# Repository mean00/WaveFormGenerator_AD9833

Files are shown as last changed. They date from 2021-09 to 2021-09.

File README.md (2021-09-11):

# WaveFormGenerator_AD9833

NB: The old version using an Arduino nano is on the legacy_atmel branch.

Simple waveform generator, using AD9833 + rotary encoder + SSD1306 oled screen.
It can output triangle/sinusoidal/rectangular waveforms.

That project is using lnArduino and requires a GD32F1/GD32F3/GD32VF1 or STM32F1 (bluepill)

Build instruction :
* edit platformConfig to specify your toolchain location
* edit mcuSelect.cmake to select your chip (default it GD32F1/STM32F1)
* mkdir build
* cd build && cmake ..
* make

Careful on the opamp.
Take one that is :
* Rail to rail
* Have high enough V/us rising time
* Have high enough gain x bandwidth ratio

With a MCP602 as amplifider, the signal is good till ~ 350 kHz
With a LM358 it's much lower, like ~ 150 kHZ

The square signal is directly from the ad9833 to avoid it being smoothed by the opamp.

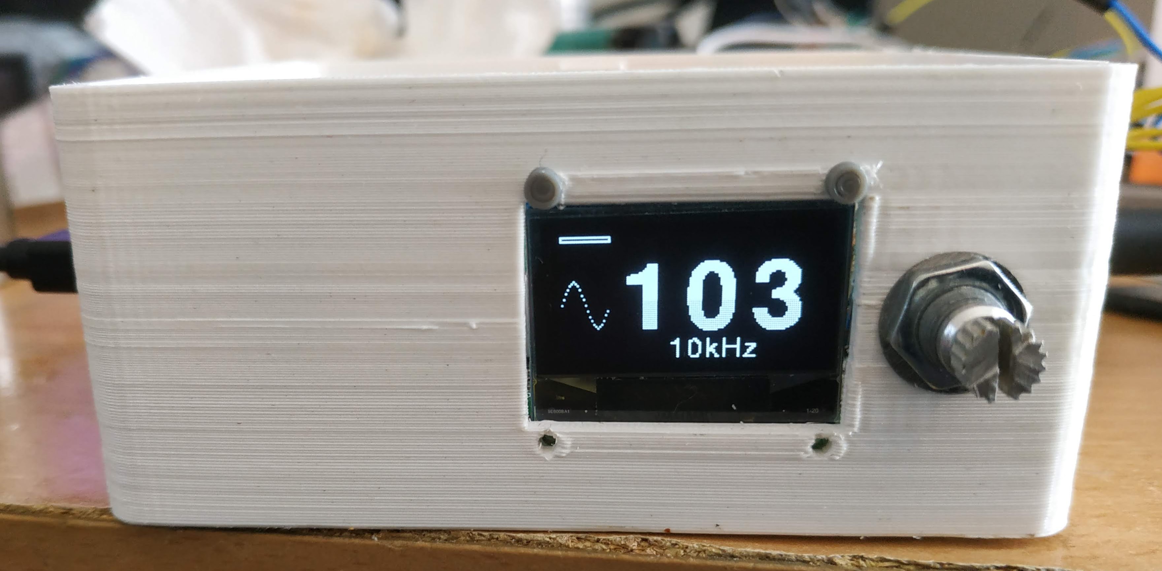
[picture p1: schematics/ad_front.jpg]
front

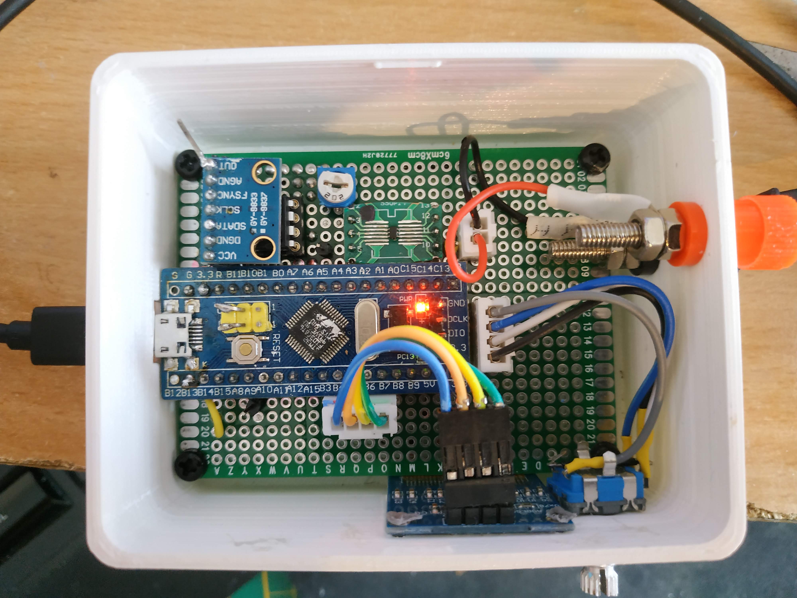
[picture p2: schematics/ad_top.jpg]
top

schem

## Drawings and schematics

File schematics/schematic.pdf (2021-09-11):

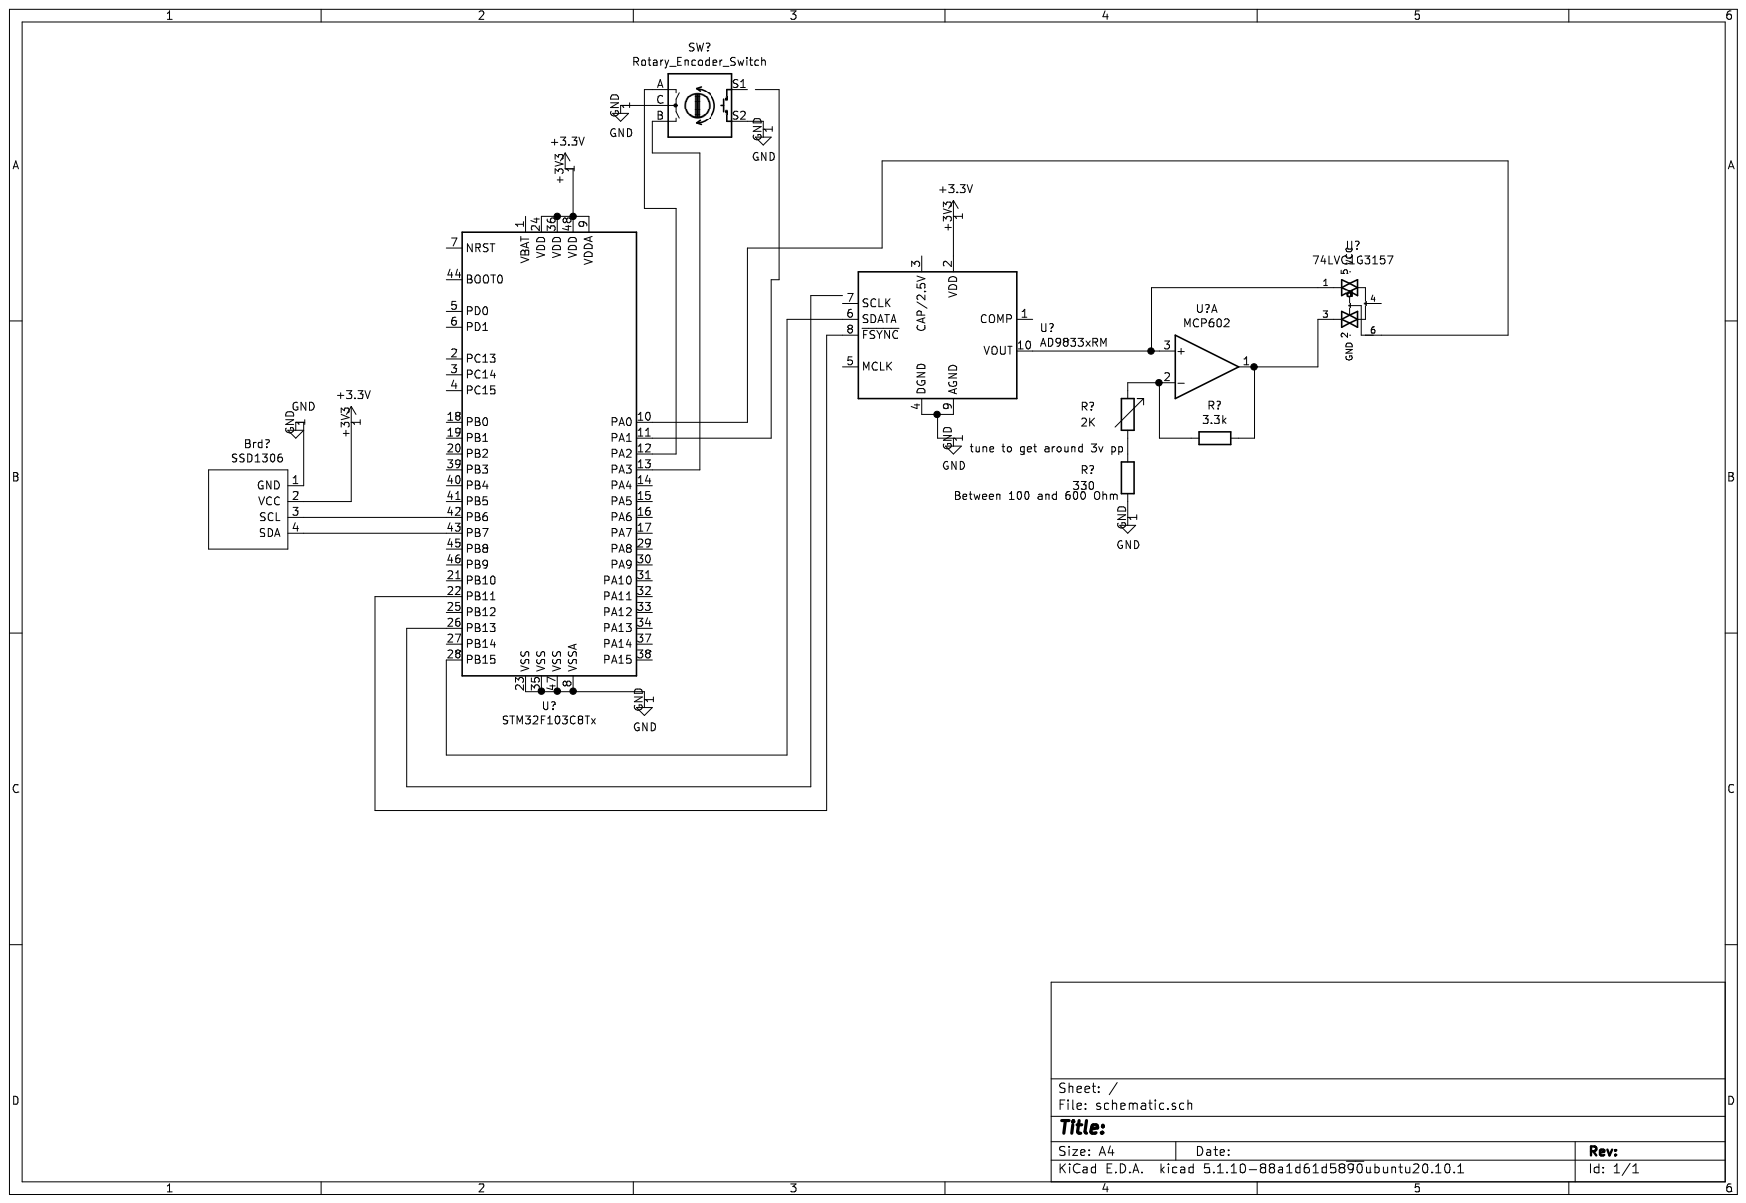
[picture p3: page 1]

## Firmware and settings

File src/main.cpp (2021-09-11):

//
//

#include "lnArduino.h"
#include "lnSPI.h"
#include "simplerAD9833.h"
#include "libraries/simplerAD9833/simplerAD9833.h"

#include "RotaryEncoder.h"

#include "libraries/simplerSSD1306/ssd1306_i2c_lnGd32vf103.h" // works also with gd32f1/Stm32f1
#include "fonts/FreeSans7pt7b.h"
#include "fonts/FreeSansBold24pt7b.h"

#include "wavePinout.h"
#include "wav_run.h"
#include "wav_display.h"

simplerAD9833 *ad;
OLED_lnGd32 *ssd1306;
lnRotary *rotary;
WavDisplay *display;
ActionInterface *action;

void amp(bool onoff)
{
    digitalWrite(AD9833_AMP, !onoff);
}

/**
 * 
 */
void setup()
{
    pinMode(LN_SYSTEM_LED,OUTPUT);    
    pinMode(AD9833_AMP,OUTPUT);    
    
    // ad9833
    
    digitalWrite(LN_SYSTEM_LED,0);
    Logger("Starting AD9833...");
    hwlnSPIClass *spi=new hwlnSPIClass(AD9833_SPI);
    ad=new simplerAD9833(spi,AD9833_CS);
    
    // ssd now
    lnI2C *i2c=new lnI2C(SSD1306_I2C,SSD1306_SPEED);
    i2c->begin(SSD1306_ADR);
    ssd1306=new OLED_lnGd32( *i2c, -1);
    ssd1306->begin();
    ssd1306->setFontFamily(&FreeSans7pt7b,&FreeSansBold24pt7b,&FreeSansBold24pt7b);
    ssd1306->setFontSize(OLEDCore::SmallFont);
    //
    display=new WavDisplay(ssd1306);
    // rotary
    rotary=new lnRotary(ROTARY_PUSH,ROTARY_LEFT,ROTARY_RIGHT);    
    action=createActionInterface();
    
}
/**
 * 
 */
void redraw()
{
    char fq[20];
    action->getFrequencyAsString(fq,19);  
    Selection sel=action->selection();
    WaveForm wf=action->getWaveForm();    
    ssd1306->clrScr();
    display->drawFrequency(fq);    
    bool hl;
    
    if(sel==TOP_SELECTION)
    {
        display->drawTab(action->selectionIndex());
    }
    
     if(sel==WAVEFORM_SELECTION) hl=true; else hl=false;
    display->displayWaveForme(wf,hl);   

    
#define DIGIT(sl,dex)     if(sel==sl) hl=true; else hl=false; \
    display->drawDigit(dex, action->getNumber(dex),hl);
    
    DIGIT(HIDIGIT_SELECTION,0)
    DIGIT(LODIGIT_SELECTION,1)
    DIGIT(SCALE_SELECTION,  2)
    
    ssd1306->update();
}
/**
 * 
 * @param fq
 * @param wf
 */
void updateAD9833(int fq, WaveForm wf)
{
    switch(wf)
    {
        case WAVE_SINE      : ad->setWaveForm(simplerAD9833::Sine);amp(true);break;
        case WAVE_TRIANGLE  : ad->setWaveForm(simplerAD9833::Triangle);amp(true);break;
        case WAVE_SQUARE    : ad->setWaveForm(simplerAD9833::Square);amp(false);break;
        default             : xAssert(0);break;
    }
    ad->setFrequency(fq);
}
/**
 * 
 */
void loop()
{
    Logger("Entering main app...\n");
    int onoff=0;
    //
    ssd1306->clrScr();
    ssd1306->update();

    
    // use safe default
    ad->setFrequency(10*1000);
    ad->setWaveForm(simplerAD9833::Sine);
    amp(true);
    ad->enable();
    
    rotary->start();
    redraw();
    while(1)
    {
       lnRotary::EVENTS  event=rotary->waitForEvent(1000);
       int count=rotary->getCount();
       if(event)
       {
            if(action->run(event,count))
            {
                updateAD9833(action->getFrequency(),action->getWaveForm());
                
                redraw();
            }
       }
    }
   
}
// EOF

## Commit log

2017-10-25 [WavForm] Switch to u8g2
2017-10-25 [wav] Fix push button + better display
2017-10-25 [wav] mostly working, need a better management of push button
2017-12-17 [wavForm] Change Fsync pin to D5 + cleanup display
2017-12-18 [waveForm] Use interrupts for rotary encoder
2017-12-18 [WavForm] Switch to interrupt driven rotary encoder
2017-12-18 [wavForm] push button, not working so well
2017-12-18 [wavForm] proper push button management
2019-08-08 [schematic] update schematic with SN74LVC3157
    [waveform.fzz]
2021-09-10 add schematic
    [schematic.kicad_pcb, schematic.sch]
2021-09-11 update schematic
2021-09-11 full schematic
    [schematic.sch]
2021-09-11 fix inverted amp + off by 10
    [main.cpp]
